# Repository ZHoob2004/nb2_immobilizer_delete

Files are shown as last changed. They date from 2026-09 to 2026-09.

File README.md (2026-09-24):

# nb2_immobilizer_delete

This board is meant to be installed on the connector pins inside the ECU and disable the immobilizer by providing affirmative responses even when a valid chip is not present.

To use, remove the ecu from the car and open the lid. Align the board with the main connector and solder the 3 circled points, then close and reinstall.

Leaving the factory immobilizer connected, turn the key to the on position and wait for a few seconds. Then turn the key off and disconnect the factory immobilizer module under the steering column.

The car should now start with any working key, regardless of chip pairing.

The rough design and firmware were taken from a miata.net thread, credit to Alcantor

https://forum.miata.net/vb/showthread.php?p=8561544#post8561544

# Build and flash instructions

This firmware targets a **bare ATtiny85 running at 1 MHz** using the calibrated 8 MHz internal RC oscillator with the `CKDIV8` fuse programmed.

## Toolchain

Install these tools:

- `avr-gcc`
- `avr-libc`
- `binutils-avr` / `avr-objcopy`
- `avrdude`

On Debian/Ubuntu/WSL:

```bash
sudo apt update
sudo apt install gcc-avr avr-libc binutils-avr avrdude
```

## Build

From the repository root:

```bash
avr-gcc \
  -Wall -Wextra -Os -std=gnu11 \
  -ffunction-sections -fdata-sections \
  -Wl,--gc-sections \
  -DF_CPU=1000000UL \
  -mmcu=attiny85 \
  -o main.elf main.c

avr-objcopy -j .text -j .data -O ihex main.elf main.hex
avr-objcopy -j .text -j .data -O binary main.elf main.bin
avr-size -C --mcu=attiny85 main.elf
```

`main.hex` is the recommended file for AVRDUDE. `main.bin` is also produced as a raw flash image for releases or other programming tools.

## 1 MHz clock fuse

Use low fuse **`0x62`**:

- internal calibrated 8 MHz RC oscillator
- `CKDIV8` programmed, giving a 1 MHz system clock
- clock output disabled
- default long startup delay retained

Only the low fuse needs to be changed for the 1 MHz clock configuration. Do **not** program `RSTDISBL`; the RESET pin is required for ISP.

You can read the existing fuses before changing anything:

```bash
avrdude -c arduino_as_isp -P COM5 -b 19200 -p t85 \
  -U lfuse:r:-:h -U hfuse:r:-:h -U efuse:r:-:h
```

Replace `COM5` with the programmer's serial port. On Linux/WSL this may be `/dev/ttyACM0` or `/dev/ttyUSB0`.

## Arduino as ISP

Load the standard **ArduinoISP** sketch onto the Arduino programmer first. The current ArduinoISP sketch uses a target SPI clock of approximately 166.7 kHz by default, specifically chosen to be safe for a 1 MHz ATtiny target.

### AVRDUDE 8.x / current programmer name

Set the 1 MHz fuse:

```bash
avrdude -c arduino_as_isp -P COM5 -b 19200 -p t85 \
  -U lfuse:w:0x62:m
```

Flash and verify the HEX file:

```bash
avrdude -c arduino_as_isp -P COM5 -b 19200 -p t85 \
  -U flash:w:main.hex:i \
  -U flash:v:main.hex:i
```

Or write the fuse and firmware in one command:

```bash
avrdude -c arduino_as_isp -P COM5 -b 19200 -p t85 \
  -U lfuse:w:0x62:m \
  -U flash:w:main.hex:i \
  -U flash:v:main.hex:i
```

### Older AVRDUDE installations

If your AVRDUDE does not recognize `arduino_as_isp`, use the STK500v1 programmer definition used by the ArduinoISP sketch:

```bash
avrdude -c stk500v1 -P COM5 -b 19200 -p t85 \
  -U lfuse:w:0x62:m \
  -U flash:w:main.hex:i \
  -U flash:v:main.hex:i
```

The `-b 19200` option is the serial link speed between the PC and the Arduino running ArduinoISP; it is **not** the ISP SCK frequency sent to the ATtiny.

## ISP wiring

ATtiny85 ISP signals are:

| ATtiny85 | ISP function |
|---|---|
| PB0 / pin 5 | MOSI |
| PB1 / pin 6 | MISO |
| PB2 / pin 7 | SCK |
| PB5 / pin 1 | RESET |
| pin 8 | VCC |
| pin 4 | GND |

The application signals are deliberately moved away from the ISP pins:

- `TX_INV` = PB3 / pin 2
- `RX_INV` = PB4 / pin 3

`RX_INV` has an external 10 kOhm pull-up, so the firmware does not enable the ATtiny internal pull-up on PB4.

## EEPROM note

The firmware stores the learned five-byte immobilizer response in EEPROM. A normal AVRDUDE flash operation may perform a chip erase, and the factory-default high fuse does **not** preserve EEPROM through chip erase.

If you intend to reflash a unit after it has learned a code, back up EEPROM first:

```bash
avrdude -c arduino_as_isp -P COM5 -b 19200 -p t85 \
  -U eeprom:r:eeprom-backup.hex:i
```

Restore it afterward if necessary:

```bash
avrdude -c arduino_as_isp -P COM5 -b 19200 -p t85 \
  -U eeprom:w:eeprom-backup.hex:i
```

Alternatively, the `EESAVE` high-fuse bit can be programmed so EEPROM survives chip erase, but that changes the high fuse and should be done deliberately rather than as part of the basic 1 MHz flashing command.

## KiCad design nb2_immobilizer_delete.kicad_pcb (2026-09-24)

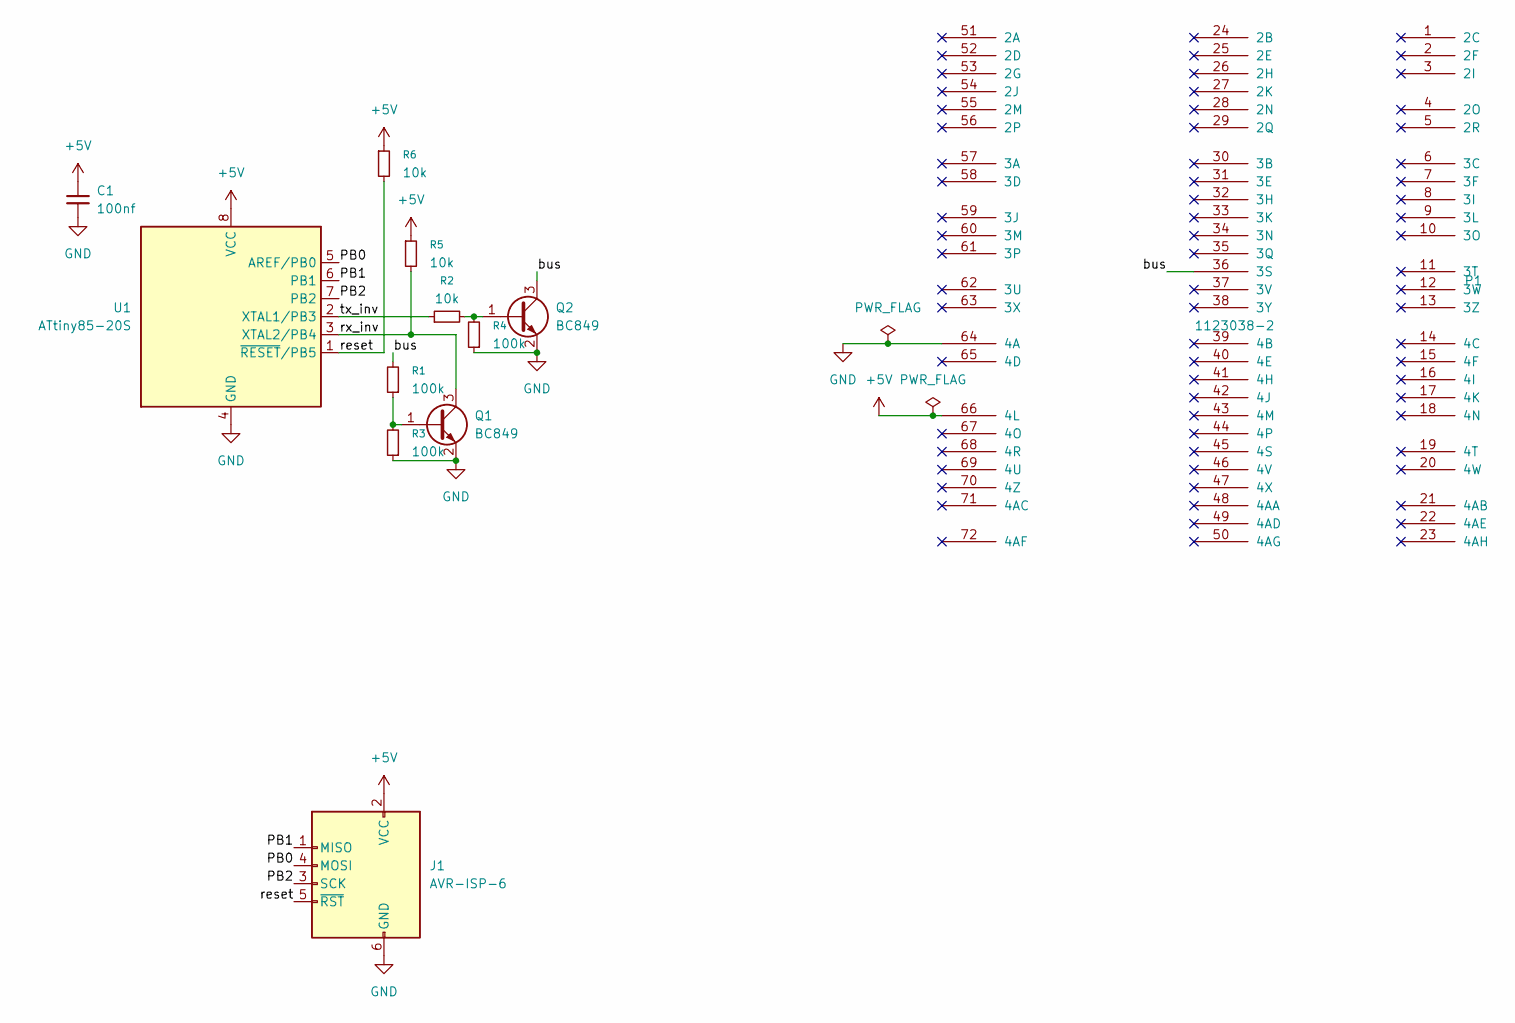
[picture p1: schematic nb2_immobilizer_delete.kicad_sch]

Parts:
C1: 100nf; C_0603_1608Metric
J1: AVR-ISP-6; Tag-Connect_TC2030-IDC-NL_2x03_P1.27mm_Vertical
P1: 1123038-2
Q1, Q2: BC849; SOT-23; LCSC Part # C334244
R1, R3, R4: 100k; R_0603_1608Metric; LCSC Part # C25803
R2, R5, R6: 10k; R_0603_1608Metric; LCSC Part # C25804
U1: ATtiny85-20S; SOIC-8_5.3x5.3mm_P1.27mm; LCSC Part # C31540447

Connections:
+5V: C1.1, J1.2 (VCC), P1.66 (4L), R5.1, R6.1, U1.8 (VCC)
/PB0: J1.4 (MOSI), U1.5 (AREF/PB0)
/PB1: J1.1 (MISO), U1.6 (PB1)
/PB2: J1.3 (SCK), U1.7 (PB2)
/bus: P1.36 (3S), Q2.3 (C), R1.2
/reset: J1.5 (~RST), R6.2, U1.1 (~RESET/PB5)
/rx_inv: Q1.3 (C), R5.2, U1.3 (XTAL2/PB4)
/tx_inv: R2.1, U1.2 (XTAL1/PB3)
GND: C1.2, J1.6 (GND), P1.64 (4A), Q1.2 (E), Q2.2 (E), R3.1, R4.1, U1.4 (GND)
unnamed: Q1.1 (B), R1.1, R3.2
unnamed: Q2.1 (B), R2.2, R4.2

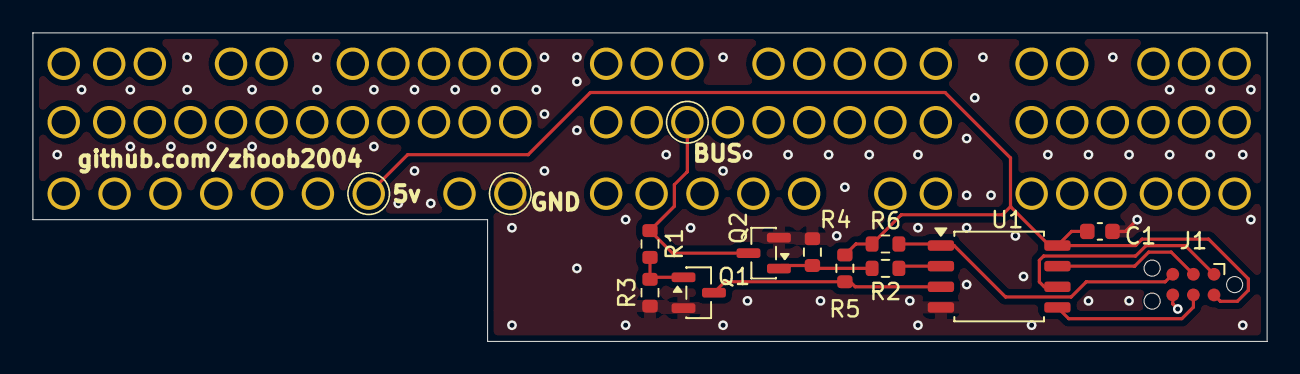
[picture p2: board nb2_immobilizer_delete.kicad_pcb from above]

Board: 2 copper layers, 76.0 x 19.0 mm, 12 parts (1 on the bottom side), 11 nets.

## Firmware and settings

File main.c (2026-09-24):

/**
 * MX5 NBFL Immobilizer Bypass for a bare ATtiny85.
 *
 * Target configuration:
 *   - F_CPU: 1 MHz (8 MHz internal RC oscillator with CKDIV8 enabled)
 *   - TX_INV: PB3
 *   - RX_INV: PB4, with an external 10 kOhm pull-up to VCC
 *   - PB0/PB1/PB2: reserved for ISP only
 */

#ifndef F_CPU
#define F_CPU 1000000UL
#endif

#if F_CPU != 1000000UL
#error "This firmware is configured for a 1 MHz ATtiny85 system clock."
#endif

#include <avr/io.h>
#include <avr/interrupt.h>
#include <avr/eeprom.h>
#include <stdint.h>

#define TX_INV_PIN PB3
#define RX_INV_PIN PB4

#define IMM_CODE_LEN 5

/*
 * Timer1 runs from the 1 MHz system clock divided by 8, giving a 125 kHz
 * timer clock. OCR1A/OCR1B intentionally retain the timing of the original
 * 16 MHz firmware, which used a /128 Timer1 prescaler and therefore the
 * same 125 kHz timer clock.
 */
#define TIMER1_COMPARE_A 80
#define TIMER1_COMPARE_B 105

enum state {
    s_idle,
    s_waitimm,
    s_learn,
    s_simulate
};

static volatile enum state g_state = s_idle;

#define is_reading_byte() (g_readed_bits != 0xFFFF)
#define is_writing_byte() (g_state == s_simulate)

static uint8_t g_imm_code_learn[IMM_CODE_LEN];
static volatile uint8_t g_imm_code[IMM_CODE_LEN];
static volatile uint8_t g_imm_answer_timeout;
static volatile uint8_t g_imm_learn_timeout;
static volatile uint16_t g_readed_bits = 0xFFFF;

static void handle_recv_byte(uint8_t byte);

int main(void)
{
    uint8_t data_in[2] = {1, 1};
    unsigned int i;

    cli();

    /*
     * PB3 is the only application output. Keep TX low so Q2 is off.
     * PB4 remains an input and uses the external 10 kOhm pull-up.
     * PB0/PB1/PB2 are unused during normal operation; enable their internal
     * pull-ups so the exposed ISP pads do not float when no programmer is
     * attached. During reset/ISP, the programming interface takes control.
     */
    DDRB = (1 << TX_INV_PIN);
    PORTB = (1 << PB0) | (1 << PB1) | (1 << PB2);

    /* Read the learned immobilizer code from EEPROM before enabling IRQs. */
    for (i = 0; i < IMM_CODE_LEN; ++i)
        g_imm_code[i] = eeprom_read_byte((uint8_t *)i);

    /*
     * Timer1:
     *   F_CPU = 1 MHz
     *   prescaler = 8 (CS12 = 1)
     *   timer clock = 125 kHz
     *
     * Compare A is used for receive sampling and compare B advances the
     * transmit/state-machine timing. Compare B ISR resets TCNT1 each bit.
     */
    TCCR1 = 0x00;
    TCNT1 = 0;
    OCR1A = TIMER1_COMPARE_A;
    OCR1B = TIMER1_COMPARE_B;

    /* Clear any pending Timer1 compare flags before enabling interrupts. */
    TIFR = (1 << OCF1A) | (1 << OCF1B);
    TIMSK = (1 << OCIE1A) | (1 << OCIE1B);

    /* Synchronous Timer1 clock, CK/8. */
    TCCR1 = (1 << CS12);

    sei();

    for (;;) {
        data_in[1] = data_in[0];
        data_in[0] = (PINB >> RX_INV_PIN) & 1;

        /* Synchronize Timer1 to either edge while not transmitting. */
        if (data_in[1] != data_in[0] && !is_writing_byte())
            TCNT1 = 0;
    }
}

/* Called after a complete byte is received from the bus. */
static void handle_recv_byte(uint8_t byte)
{
    static uint8_t cur_byte;
    unsigned int i;

    switch (g_state) {
    case s_idle:
        /* PCM immobilizer request. */
        if (byte == 0x0E) {
            /* Wait briefly to see whether the original immobilizer answers. */
            cur_byte = 0;
            g_imm_answer_timeout = 5;
            g_state = s_waitimm;
        }
        break;

    case s_learn:
        g_imm_code_learn[cur_byte++] = byte;
        if (cur_byte >= IMM_CODE_LEN) {
            g_state = s_idle;

            /* Store only changed bytes to reduce EEPROM wear. */
            for (i = 0; i < IMM_CODE_LEN; ++i) {
                if (g_imm_code[i] != g_imm_code_learn[i]) {
                    g_imm_code[i] = g_imm_code_learn[i];
                    eeprom_write_byte((uint8_t *)i, g_imm_code[i]);
                }
            }
        }
        break;

    default:
        break;
    }
}

/*
 * Timer1 compare A: sample at approximately 75% of the current bit period.
 * A complete frame is one start bit followed by eight data bits.
 */
ISR(TIMER1_COMPA_vect)
{
    if (is_writing_byte())
        return;

    g_readed_bits = (g_readed_bits << 1) |
                    (((uint8_t)(~PINB) >> RX_INV_PIN) & 1);

    /* Bit 9 is the inverted start bit; when it is zero, a byte is complete. */
    if ((g_readed_bits & 0x0100) == 0) {
        handle_recv_byte((uint8_t)g_readed_bits & 0xFF);
        g_readed_bits = 0xFFFF;
    }
}

/* Timer1 compare B: end-of-bit timing and transmit state machine. */
ISR(TIMER1_COMPB_vect)
{
    static uint8_t cur_byte = 0;
    static uint8_t cur_bit = 9;

    TCNT1 = 0;

    switch (g_state) {
    case s_waitimm:
        if (g_imm_answer_timeout > 0) {
            if (is_reading_byte()) {
                g_imm_learn_timeout = 176;
                g_state = s_learn;
            } else {
                --g_imm_answer_timeout;
            }
        } else {
            g_state = s_simulate;
        }
        break;

    case s_learn:
        if (g_imm_learn_timeout > 0)
            --g_imm_learn_timeout;
        else
            g_state = s_idle;
        break;

    case s_simulate:
        if (cur_bit > 9 || cur_bit == 0) {
            /* Idle/space: TX low, Q2 off, bus released. */
            PORTB &= ~(1 << TX_INV_PIN);
        } else if (cur_bit == 9) {
            /* Start bit: TX high, Q2 on, bus pulled low. */
            PORTB |= (1 << TX_INV_PIN);
        } else {
            /* Data bits, LSB first, with the external transistor inversion. */
            if (g_imm_code[cur_byte] & (1 << (cur_bit - 1)))
                PORTB &= ~(1 << TX_INV_PIN); /* Logic 1 */
            else
                PORTB |= (1 << TX_INV_PIN);  /* Logic 0 */
        }

        if (cur_bit > 0) {
            --cur_bit;
        } else {
            cur_bit = 18; /* 18..10 space, 9 start, 8..1 data, 0 idle */
            ++cur_byte;

            if (cur_byte >= IMM_CODE_LEN) {
                /* No space before the first byte; waitimm supplied the delay. */
                cur_bit = 9;
                cur_byte = 0;
                g_state = s_idle;
            }
        }
        break;

    default:
        break;
    }
}

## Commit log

2026-09-21 first draft
    [nb2_immobilizer_delete.kicad_pcb, nb2_immobilizer_delete.kicad_sch]
2026-09-22 added capacitor, dnp tag-connect
    [nb2_immobilizer_delete.kicad_pcb, nb2_immobilizer_delete.kicad_sch]
2026-09-24 revised layout for robustness, reduced clock to 1mhz, added github actions workflow
    [nb2_immobilizer_delete.kicad_pcb, nb2_immobilizer_delete.kicad_sch]
2026-09-24 updated production files
    [nb2_immobilizer_delete.kicad_pcb]
